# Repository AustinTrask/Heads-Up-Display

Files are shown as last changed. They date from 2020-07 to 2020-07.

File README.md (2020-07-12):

# Heads-Up-Display
CAD models, parts lists, and CircuitPython script for a dashboard-mounted automobile HUD.

I decided to put this project aside as of July 2020 because the lid deformed inward due to the high summer heat and the weight of the lens on it. I fear that any engineered solution would not be enough. I printed the parts on a Prusa Mini in Prusament PETG.

-----------------------------------------------------------------------------------------------------------------

Purchased Part List:

Adafruit Feather M4 Express

Adafruit Ultimate GPS Featherwing

Adafruit LSM303DLHC Compass + Accelerometer

Adafruit 128x32 OLED Featherwing

Half-sized breadboard

Mirrors Darice Craft Mini Square, 3 inches, 5 Pieces from Amazon, ASIN B004HGODQU

SupremeTech 12 x 12 x 0.04 Inch Acrylic See-Through Mirror, 30% Transparent from Amazon, ASIN B017ONH3EG

Double Convex Lens, 100mm Focal Length, 3" (75mm) Diameter - Spherical, Optically Worked Glass Lens - Ground Edges, Polished - Great for Physics Classrooms - Eisco Labs from Amazon, ASIN B076QKKCXJ

-----------------------------------------------------------------------------------------------------------------

General Information:

If I update the Solidworks files, I will try to update the corresponding .STL files as well.

The acrylic is cut to 2.8"x3" for the viewing piece.

The screws I used to secure the display and the lens parts are simply machine screws and nuts I had. I don't know the true size. Adjust the parts as necesary.

The part titled "HUD_Dash_Mount_v1" is modeled to fit my 2012 Toyota Highlander at my prefered viewing angle. I recommend editing the sketches that define the bounds of the loft as well as the spline that the loft follows to best fit your car and head position.

The .py file is a CircuitPython script that uses the RMC data from the GPS to get the speed. If you think I'm a dumbass for not using the OBD-II port, you're probably right. Too bad. Do it your way. My way still remained accurate to within 2 MPH of the car's speedometer but with a lacking refresh rate.

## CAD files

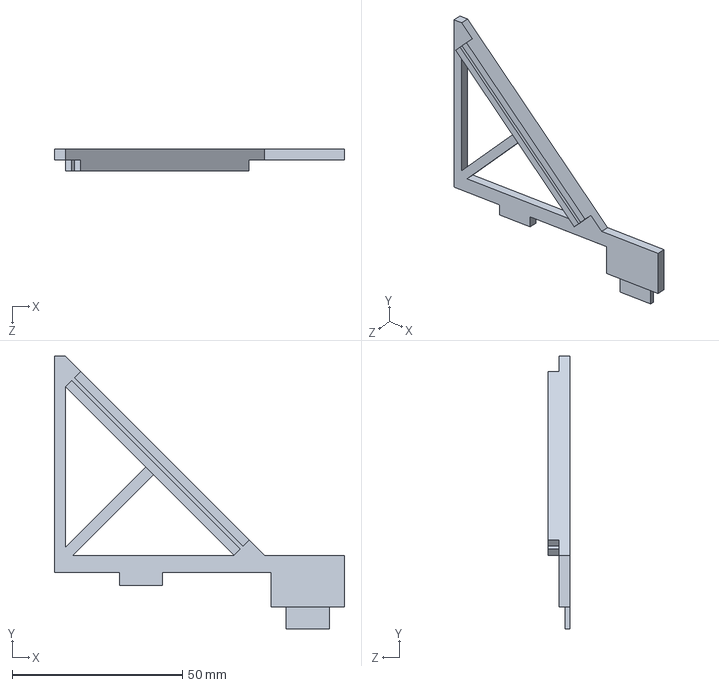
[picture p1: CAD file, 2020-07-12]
3D Printed Parts/HUD_Reflector_Brace_L.SLDPRT
85.1 x 80.0 x 6.35 mm

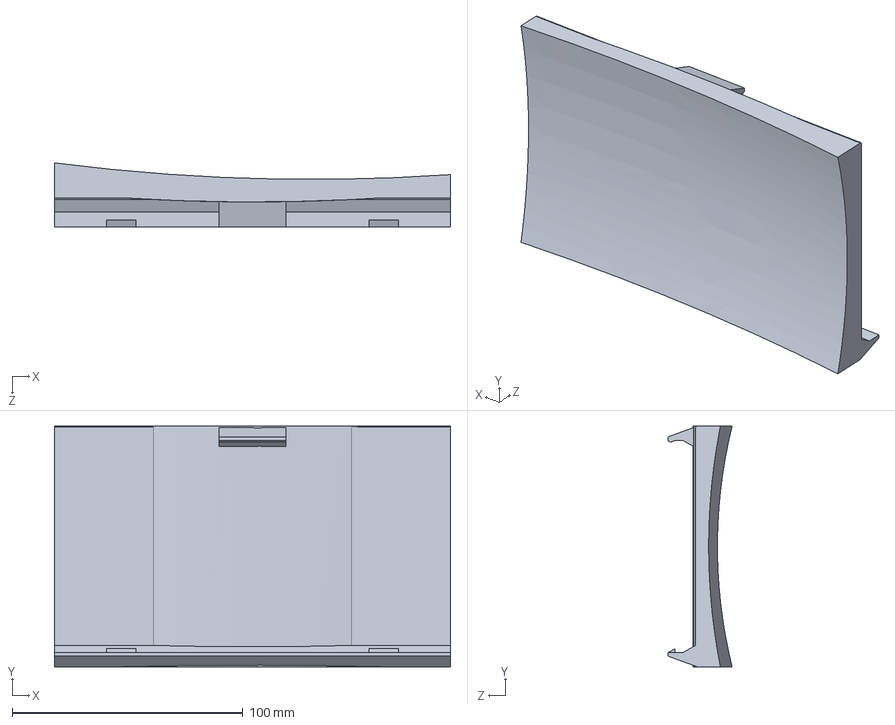
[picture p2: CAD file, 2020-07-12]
3D Printed Parts/HUD_Dash_Mount_v1.SLDPRT
171.4 x 104.1 x 27.8 mm

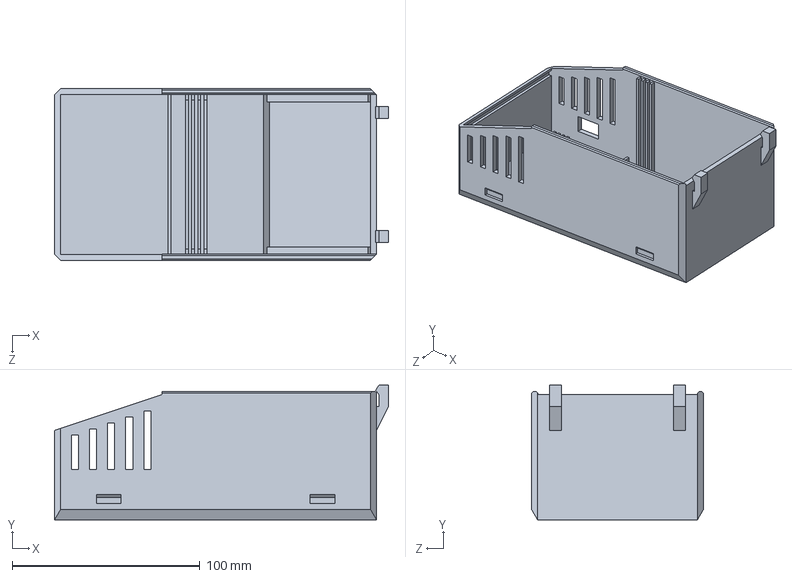
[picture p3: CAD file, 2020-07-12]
3D Printed Parts/HUD_Box_v2.SLDPRT
177.8 x 71.8 x 91.4 mm

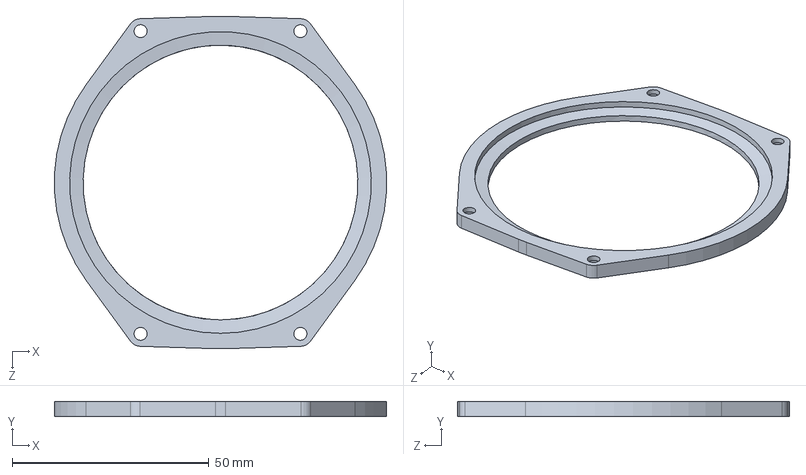
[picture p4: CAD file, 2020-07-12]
3D Printed Parts/HUD_Lens_v2.SLDPRT
84.4 x 3.81 x 84.5 mm

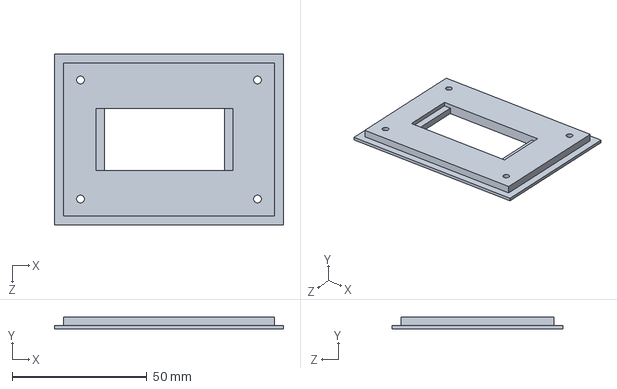
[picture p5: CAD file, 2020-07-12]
3D Printed Parts/HUD_Box_Screen_Plate_v2.SLDPRT
85.1 x 4.45 x 63.5 mm

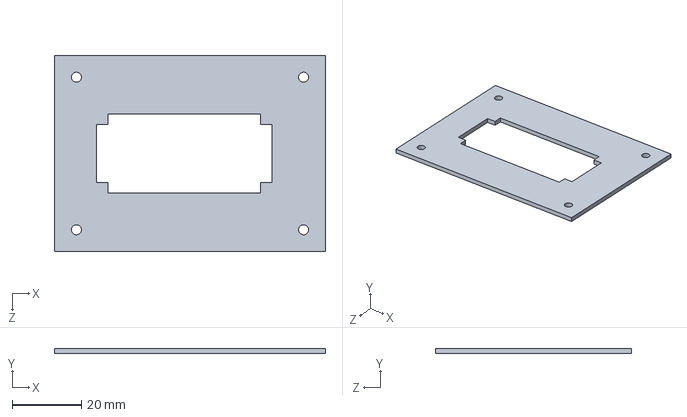
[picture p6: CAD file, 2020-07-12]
3D Printed Parts/HUD_Box_Screen_Plate_Attach.SLDPRT
78.5 x 1.59 x 56.9 mm

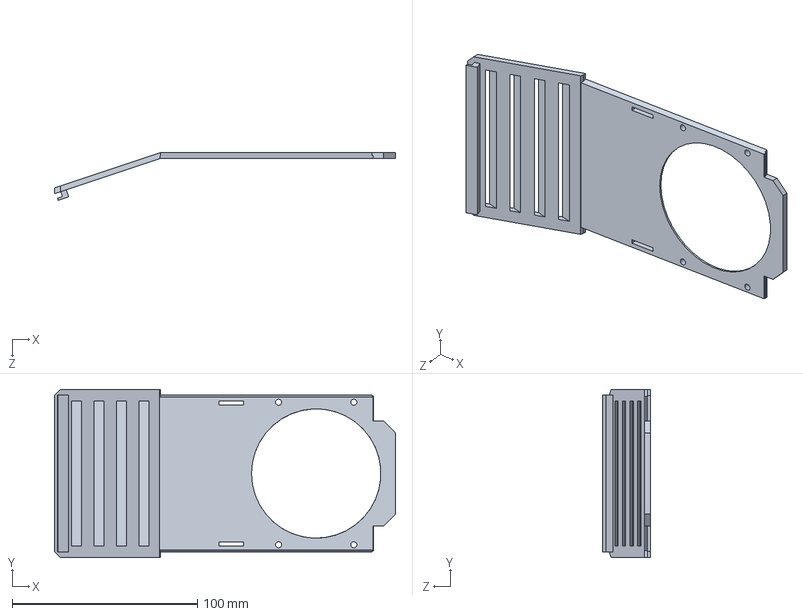
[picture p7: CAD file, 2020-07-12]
3D Printed Parts/HUD_Box_Lid_v1.SLDPRT
184.1 x 90.9 x 25.8 mm

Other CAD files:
3D Printed Parts/HUD_Reflector_Brace_R.SLDPRT
3D Printed Parts/HUD_Box_Lid_v1.STL
3D Printed Parts/HUD_Box_Screen_Plate_Attach.STL
3D Printed Parts/HUD_Box_Screen_Plate_v2.STL
3D Printed Parts/HUD_Box_v2.STL
3D Printed Parts/HUD_Dash_Mount_v1.STL
3D Printed Parts/HUD_Lens_v2.STL
3D Printed Parts/HUD_Reflector_Brace_L.STL
3D Printed Parts/HUD_Reflector_Brace_R.STL

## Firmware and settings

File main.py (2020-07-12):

import time
import board
import busio
import digitalio
import math
import displayio
import terminalio

from adafruit_display_text import label
import adafruit_gps
import adafruit_lsm303dlh_mag
import adafruit_displayio_ssd1306

displayio.release_displays()

button0 = digitalio.DigitalInOut(board.A0)
button0.direction = digitalio.Direction.INPUT
button0.pull = digitalio.Pull.DOWN

button1 = digitalio.DigitalInOut(board.A1)
button1.direction = digitalio.Direction.INPUT
button1.pull = digitalio.Pull.DOWN

button2 = digitalio.DigitalInOut(board.A2)
button2.direction = digitalio.Direction.INPUT
button2.pull = digitalio.Pull.DOWN

button3 = digitalio.DigitalInOut(board.A3)
button3.direction = digitalio.Direction.INPUT
button3.pull = digitalio.Pull.DOWN

RX = board.RX
TX = board.TX

uart = busio.UART(TX, RX, baudrate=9600, timeout=1)
gps = adafruit_gps.GPS(uart, debug=False)


i2c = board.I2C()
mag = adafruit_lsm303dlh_mag.LSM303DLH_Mag(i2c)

display_bus = displayio.I2CDisplay(i2c, device_address=0x3c)
display = adafruit_displayio_ssd1306.SSD1306(display_bus, width=128, height=32)

splash = displayio.Group(max_size=3)
display.show(splash)

color_bitmap = displayio.Bitmap(128, 32, 1)
color_palette = displayio.Palette(1)
color_palette[0] = 0x000000

#bg_sprite = displayio.TileGrid(color_bitmap, pixel_shader=color_palette, x=0, y=0)
#splash.append(bg_sprite)

last_print = time.monotonic()
current = time.monotonic()
old = current
count = 0
bearing = 0
p = math.pi

speed_unit = 1
speed_disp = 0
speed_kts = 0

def speedConvert(speed_kts, speed_unit):
    #print(speed_kts)
    if speed_unit == 0:
        speed_disp = speed_kts
        #print(speed_disp)
        unit_disp = 'KTS'
    elif speed_unit == 1:
        speed_disp = 1.151 * speed_kts
        unit_disp = 'MPH'
    elif speed_unit == 2:
        speed_disp = 1.852 * speed_kts
        unit_disp = 'KPH'
    elif speed_unit == 3:
        speed_disp = .5144 * speed_kts
        unit_disp = 'M/S'
    return(speed_disp, unit_disp)

def formatSpeed(speed_disp):
    if speed_disp < 1:
        speedForm = str(0)
    elif speed_disp < 10:
        speedForm = str(speed_disp)[:1]
    elif speed_disp < 100:
        speedForm = str(speed_disp)[:2]
    else:
        speedForm = str(speed_disp)[:3]
    return(speedForm)

def formatBearing(bearing):
    if bearing < 1:
        bearingForm = str(0)
    elif bearing < 10:
        bearingForm = str(bearing)[:1]
    elif bearing < 100:
        bearingForm = str(bearing)[:2]
    else:
        bearingForm = str(bearing)[:3]
    return(bearingForm)

def getBearing(x,y):
    #calculate bearing and return it
    if x >= 0 and y >= 0:
        bearing = (180 / p) * math.atan(y/x)
    elif x < 0:
        bearing = 180 + ((180 / p) * math.atan(y/x))
    else:
        bearing = 360 + ((180 / p) * math.atan(y/x))
    return(bearing)

while True:

    hasLock = True
    #if button0.value:
    #    speed_unit = 0
    #elif button1.value:
    #    speed_unit = 1
    #elif button2.value:
    #    speed_unit = 2
    #elif button3.value:
    #    speed_unit = 3

    current = time.monotonic()
    count = count + 1

    if uart.in_waiting > 0:
        gps_string = uart.readline()
        print(gps_string)
        if "GPRMC" in gps_string:
            old = current
            #print(gps_string)
            gps_string_conv = str(gps_string, 'ascii')
            #print(gps_string_conv)
            gps_array = gps_string_conv.split(',')
            #print(gps_array[7])
            speed_kts = float(gps_array[7])
            #print(speed_kts)

    try:
        testArray = gps_array
    except:
        hasLock = False


    if count == 2:
        count = 0

        x = mag.magnetic[0]
        y = mag.magnetic[1]

        if x == 0:
            x = 0.00001

        bearing = getBearing(x,y)

        (speed_disp, unit_disp) = speedConvert(speed_kts, speed_unit)

        speedForm = formatSpeed(speed_disp)
        bearingForm = formatBearing(bearing)

        try:
            if gps_array[4] != 'N' and gps_array[4] != 'S':
                hasLock = False
        except:
            useless = True

        if hasLock == False:
            speedForm = 'NL'

        ln1 = speedForm
        ln2 = unit_disp
        ln3 = bearingForm

        text_area1 = label.Label(terminalio.FONT, text=ln1, color=0xFFFFFF, x=41, y=10)
        text_area2 = label.Label(terminalio.FONT, text=ln2, color=0xFFFFFF, x=66, y=10)
        text_area3 = label.Label(terminalio.FONT, text=ln3, color=0xFFFFFF, x=54, y=20)

        splash = displayio.Group(max_size=3)
        display.show(splash)

        splash.append(text_area1)
        splash.append(text_area2)
        splash.append(text_area3)

    time.sleep(.05)
